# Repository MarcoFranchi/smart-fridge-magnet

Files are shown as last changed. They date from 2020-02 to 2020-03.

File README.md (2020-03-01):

# smart-fridge-magnet
Fridge magnet with 4.2" eInk display for HomeAssistant

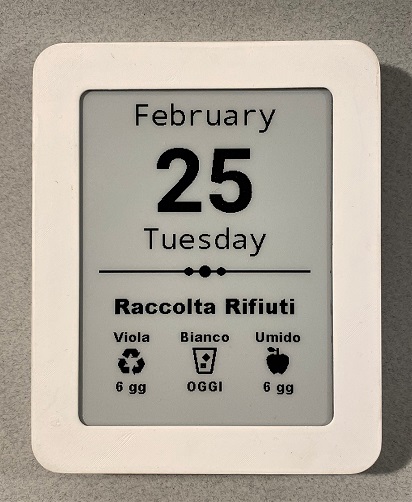
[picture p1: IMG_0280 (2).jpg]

## Bill off Material
* 1 Box prineted in 3D (three pieces)
* 4 Screws M3x12mm 
* 4 Bolts M3
* 4 Neodymium magnets 10x2mm
* 6 Pieces of beryllium copper sheet arround 18x7mm or other thing for battery contact
* 30cm Of electric wire
* 1 eInk display 4.2" [here](https://www.waveshare.com/e-Paper-ESP8266-Driver-Board.htm) or Anazon, ebay, etc.
* 1 ESP8266 Driver Board [here](https://www.waveshare.com/product/displays/e-paper/epaper-2/4.2inch-e-paper.htm) or Anazon, ebay, etc.
* Cyanoacrylate Glue
* Matt white paint (optional if you want a good finishing)
## Build and program it
* Print in 3D the case, frame and cover using .igs or .step file, best choice is ABS
* Install the Fonts (copy all .ttf in ./fonts ESP folder) 
* Copy the display_1.yaml in ESP folder and compile it
* Replace your WiFi configuration in line 12, 13, 16, 17 and your API and OTA password in line 31 34, replace also your calendar's entity_id in line 97   
* Flash the ESP8266 Driver Board with .bin file using USB

TIP: for installation and test comment the DeepSleep declaration (line 20-24) before comiling otherwise you will wait one hour before you can make other changes.
## Home Assistant configuration
### Install Home Assistant dependence 
* [Garbage Collection](https://github.com/bruxy70/Garbage-Collection) from HACS
* [Google Calendar Event](https://www.home-assistant.io/integrations/calendar.google/) from HA integration
### Edit configuration.yaml
* Merge the display configuration.jaml with your configuration.jaml file or split it in a differten file if you use include files

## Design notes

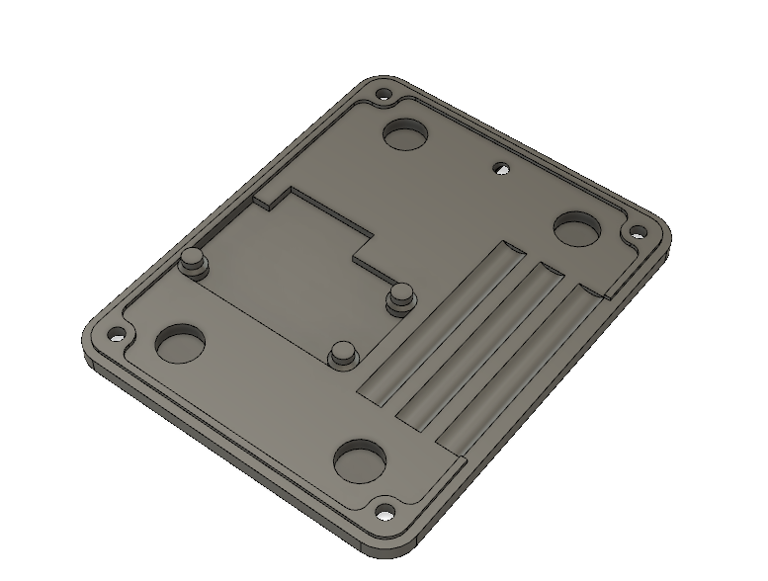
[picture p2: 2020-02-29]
case/Cover.PNG

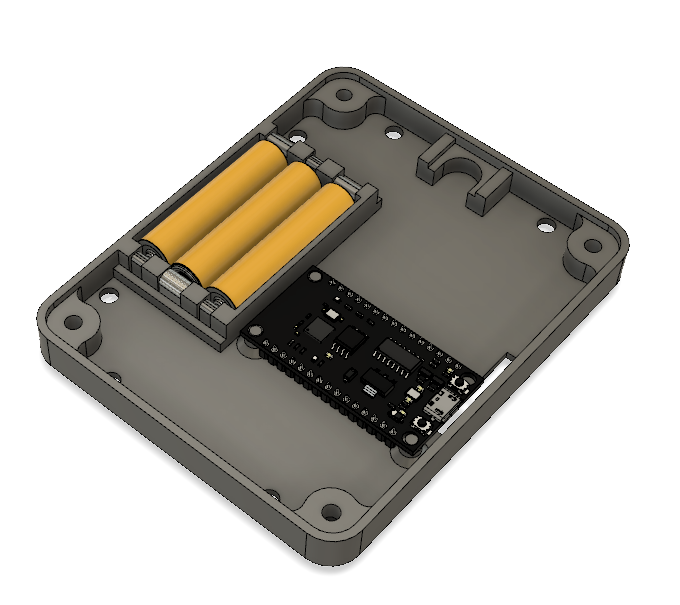
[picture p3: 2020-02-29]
case/Box.PNG

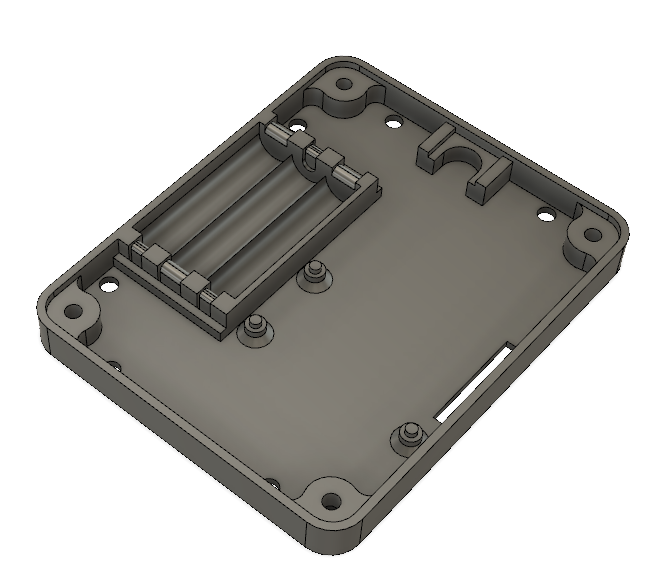
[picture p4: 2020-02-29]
case/Box2.PNG

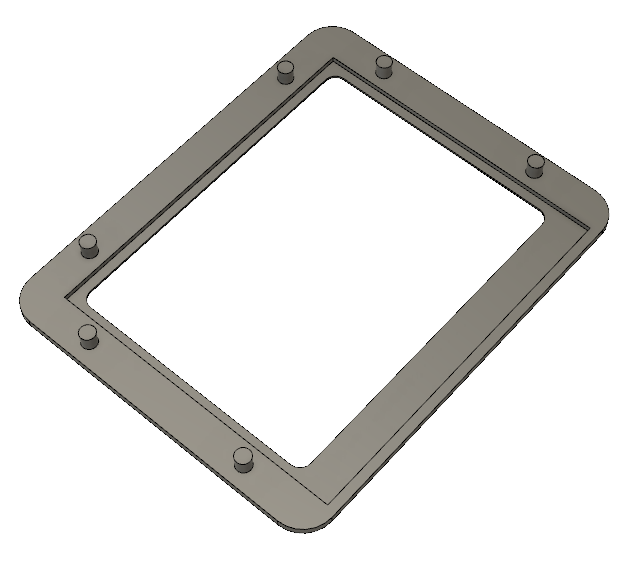
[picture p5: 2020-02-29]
case/Frame.PNG

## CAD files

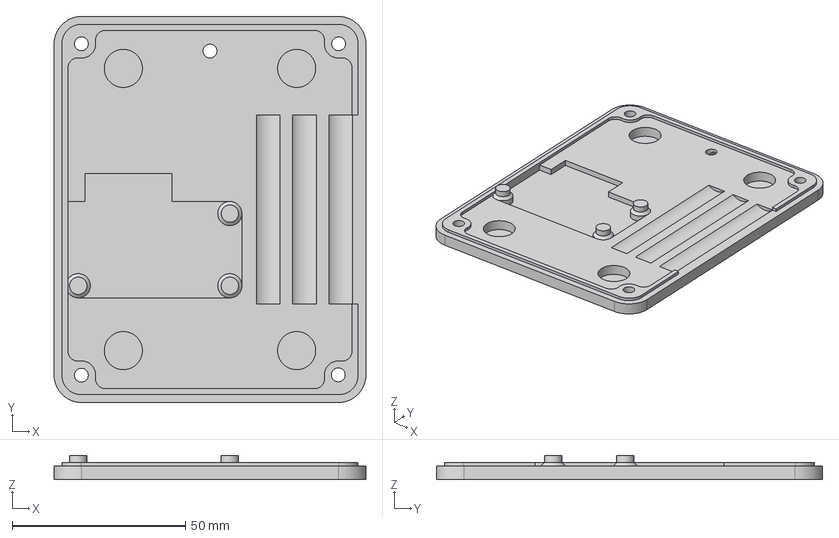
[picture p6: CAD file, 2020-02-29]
case/Cover v30.step
90.0 x 111.4 x 7.00 mm

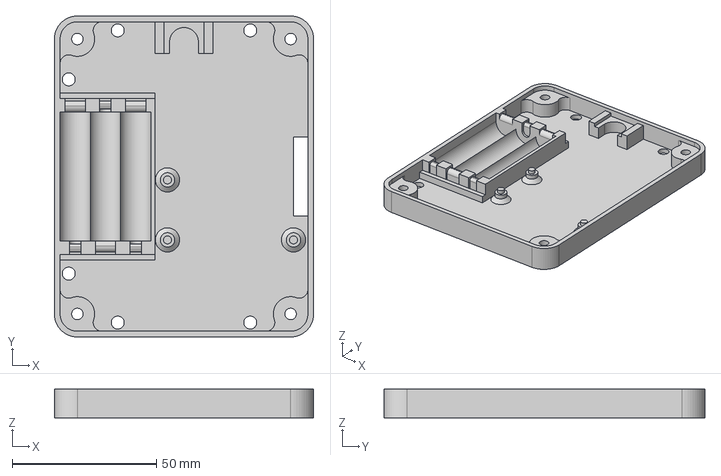
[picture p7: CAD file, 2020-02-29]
case/Box v37.step
90.0 x 111.4 x 10.0 mm

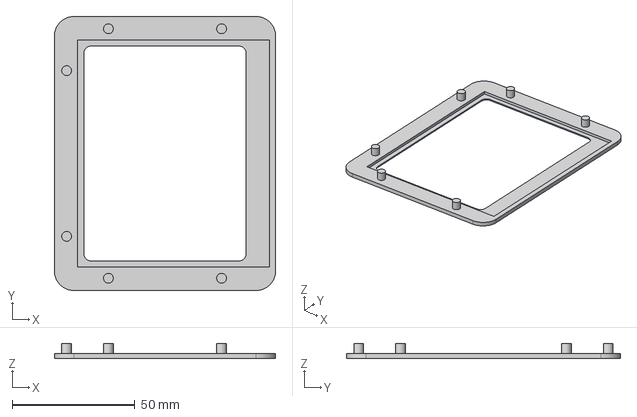
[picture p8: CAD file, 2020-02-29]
case/FrameF v8.step
90.0 x 111.4 x 6.00 mm

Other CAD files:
case/Box v37.iges
case/Cover v30.iges
case/FrameF v8.iges
case/Smart-FrameV2 v15.f3z

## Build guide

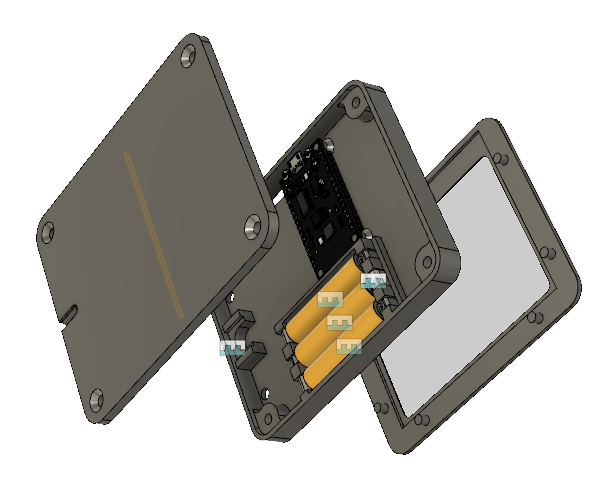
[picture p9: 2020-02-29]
case/Assembly.PNG

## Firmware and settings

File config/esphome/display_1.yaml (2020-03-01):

esphome:
  name: "display_1"
  platform: ESP8266
  board: nodemcuv2
  on_boot:
    priority: -100
    then:
      - delay: 30s
      - component.update: epaper

wifi:
  ssid: "WiFi-Casa"
  password: "yourpassword"
  reboot_timeout: 0s
  manual_ip:
    static_ip: DisplayIPAddress
    gateway: YourGatewayIP
    subnet: 255.255.255.0

# Sleep Cycle
deep_sleep:
  id: deep_sleep_1
  run_duration: 40s
  sleep_duration: 60min

# Enable logging
logger:

# Enable Home Assistant API
api:
  password: "yourpassword"

ota:
  password: "yourpassword"

# SPI 
spi:
  clk_pin: GPIO14
  mosi_pin: GPIO13
  miso_pin: GPIO12

#  Time
time:
  - platform: homeassistant
    id: current_time
    timezone: Europe/Rome

# Sensors
binary_sensor:
  - platform: status
    id: connection_status
    internal: true
    
sensor:
  - platform: homeassistant
    id: sacco_trasparente
    entity_id: sensor.sacco_trasparente
    internal: true
  - platform: homeassistant
    id: sacco_viola
    entity_id: sensor.sacco_viola
    internal: true
  - platform: homeassistant
    id: compostabile
    entity_id: sensor.compostabile
    internal: true
  - platform: homeassistant
    id: days_sacco_trasparente
    entity_id: sensor.days_sacco_trasparente
    internal: true
  - platform: homeassistant
    id: days_sacco_viola
    entity_id: sensor.days_sacco_viola
    internal: true
  - platform: homeassistant
    id: days_compostabile
    entity_id: sensor.days_compostabile
    internal: true
    
  - platform: adc
    pin: VCC
    id: vcc
    name: "Display_1 Battery Level"
    unit_of_measurement: "%"
    filters:
    - calibrate_linear:
        - 3.0 -> 100.0
        - 1.6 -> 0.0
    
  - platform: wifi_signal
    name: "Display_1 WiFi Signal Sensor"
    update_interval: 120s

text_sensor:
  - platform: homeassistant
    id: calendar
    entity_id: calendar.YourCalendar
    internal: true   
  - platform: homeassistant
    id: calendar_message
    entity_id: sensor.calendar_message
    internal: true
  - platform: homeassistant
    id: calendar_description
    entity_id: sensor.calendar_description
    internal: true
    
  - platform: homeassistant
    id: icon
    entity_id: sensor.text_icon
    internal: true
  - platform: homeassistant
    id: text
    entity_id: input_text.display_text_title
    internal: true
  - platform: homeassistant
    id: text1
    entity_id: input_text.display_text_line1
    internal: true
  - platform: homeassistant
    id: text2
    entity_id: input_text.display_text_line2
    internal: true
  - platform: homeassistant
    id: text3
    entity_id: input_text.display_text_line3
    internal: true
 
  - platform: homeassistant
    id: moon_icon
    entity_id: sensor.moon_tpl

  - platform: homeassistant
    id: forecast_today_icon
    entity_id: sensor.forecast_today_icon

# Fonts
font:
  - file: 'fonts/ARIBL0.ttf'
    id: content_font
    size: 16

  - file: 'fonts/ARIBL0.ttf'
    id: title_font
    size: 26
    
  - file: 'fonts/Roboto-Bold.ttf'
    id: clock_font
    size: 110
    glyphs: [0, 1, 2, 3, 4, 5, 6, 7 ,8, 9]

  - file: 'fonts/DroidSansMono.ttf'
    id: temp_font
    size: 36
    glyphs:
      ['&', '@', '!', ',', '.', '"', '%', '(', ')', '+', '-', '_', ':', '°', '0',
       '1', '2', '3', '4', '5', '6', '7', '8', '9', 'A', 'B', 'C', 'D', 'E',
       'F', 'G', 'H', 'I', 'J', 'K', 'L', 'M', 'N', 'O', 'P', 'Q', 'R', 'S',
       'T', 'U', 'V', 'W', 'X', 'Y', 'Z', ' ', 'a', 'b', 'c', 'd', 'e', 'f',
       'g', 'h', 'i', 'j', 'k', 'l', 'm', 'n', 'o', 'p', 'q', 'r', 's', 't',
       'u', 'v', 'w', 'x', 'y', 'z','ì', 'ä', 'ö', '/']

  - file: 'fonts/materialdesignicons-webfont.ttf'
    id: icon_font_xxl
    size: 200
    glyphs: [
      "󰊉", # mdi-battery-off-outline
      "", # mdi-wifi-off
      ]

  - file: 'fonts/materialdesignicons-webfont.ttf'
    id: icon_font_xl
    size: 88
    glyphs: [
      "", # mdi-alert-outline
      "", # mdi-reminder
      "ﷺ", # mdi-calendar-month
      "﩯", # mdi-silverware-fork-knife
      "󰃶", # mdi-alien-outline
      "", # mdi-emoticon-happy-outline
      
      "", # mdi-weather-night
      "", # mdi-weather-cloudy
      "", # mdi-weather-fog
      "", # mdi-weather-hail
      "", # mdi-weather-lightning 
      "", # mdi-weather-lightning-rainy
      "", # mdi-weather-partly-cloudy
      "", # mdi-weather-pouring
      "", # mdi-weather-rainy
      "", # mdi-weather-snowy
      "", # mdi-weather-snowy-rainy
      "", # mdi-weather-sunny
      "", # mdi-weather-windy
      "", # mdi-weather-windy-variant
      "" # mdi-weather-hurricane
      ]
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
